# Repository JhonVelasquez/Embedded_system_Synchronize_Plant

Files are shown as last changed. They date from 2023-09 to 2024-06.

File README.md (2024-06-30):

# Embedded_system_Synchronize_Plant
Project of a embedded system  that synchronizes signals in a plant. There is electronic (PCB) and software design (FreeRTOS for STM32F7).

## Required Embedded System - Plant:
The embedded system in the pictures is what is needed for interacting with the Plant, it must send pulses and TCP messages in a specific pattern every time there is a new object incoming the plant.
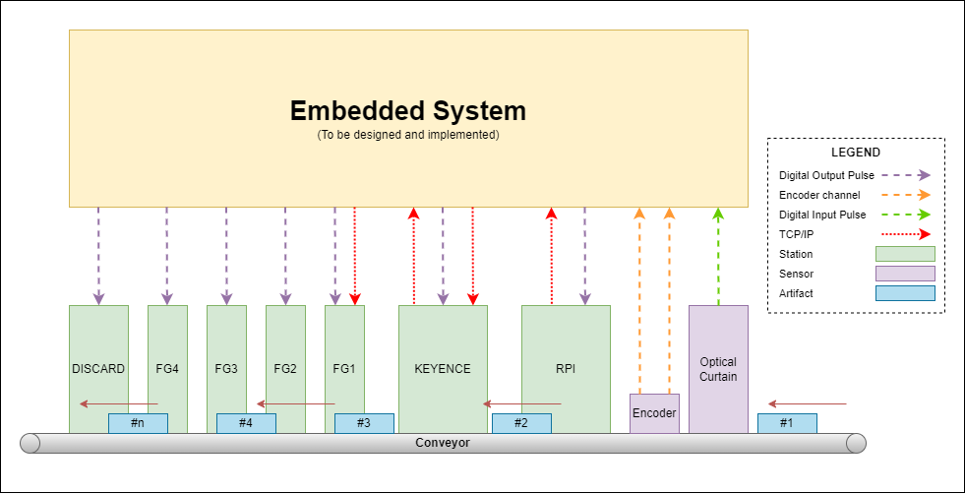
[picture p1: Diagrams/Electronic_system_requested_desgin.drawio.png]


## HARDWARE:

The following PCB collects all the electronics part of the dessigned Embedded system
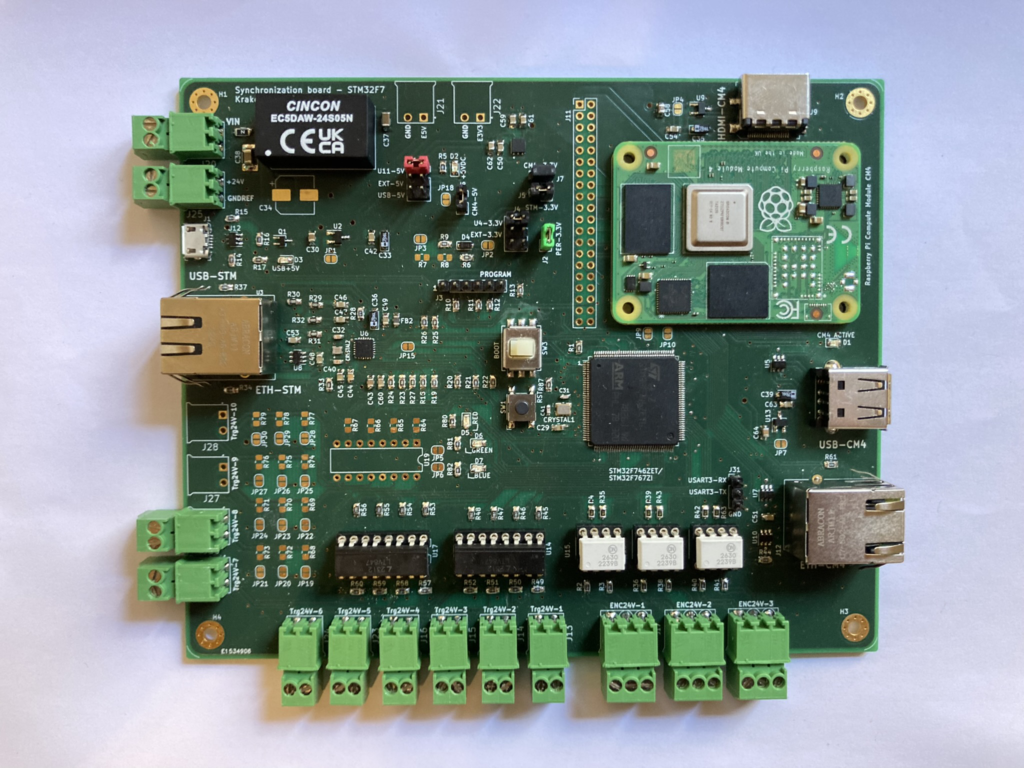
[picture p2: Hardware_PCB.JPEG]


Diagram of the electronics sections. The PCB was made based on it.
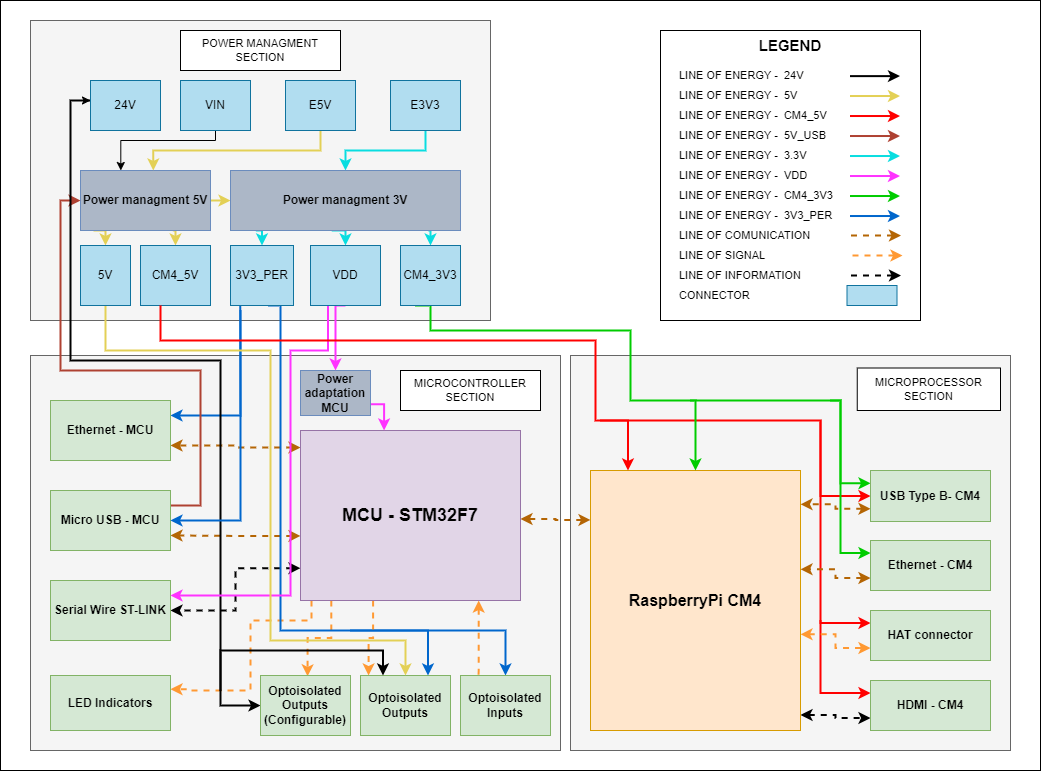
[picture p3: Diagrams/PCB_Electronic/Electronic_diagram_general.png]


Main sub-systems of the PCB
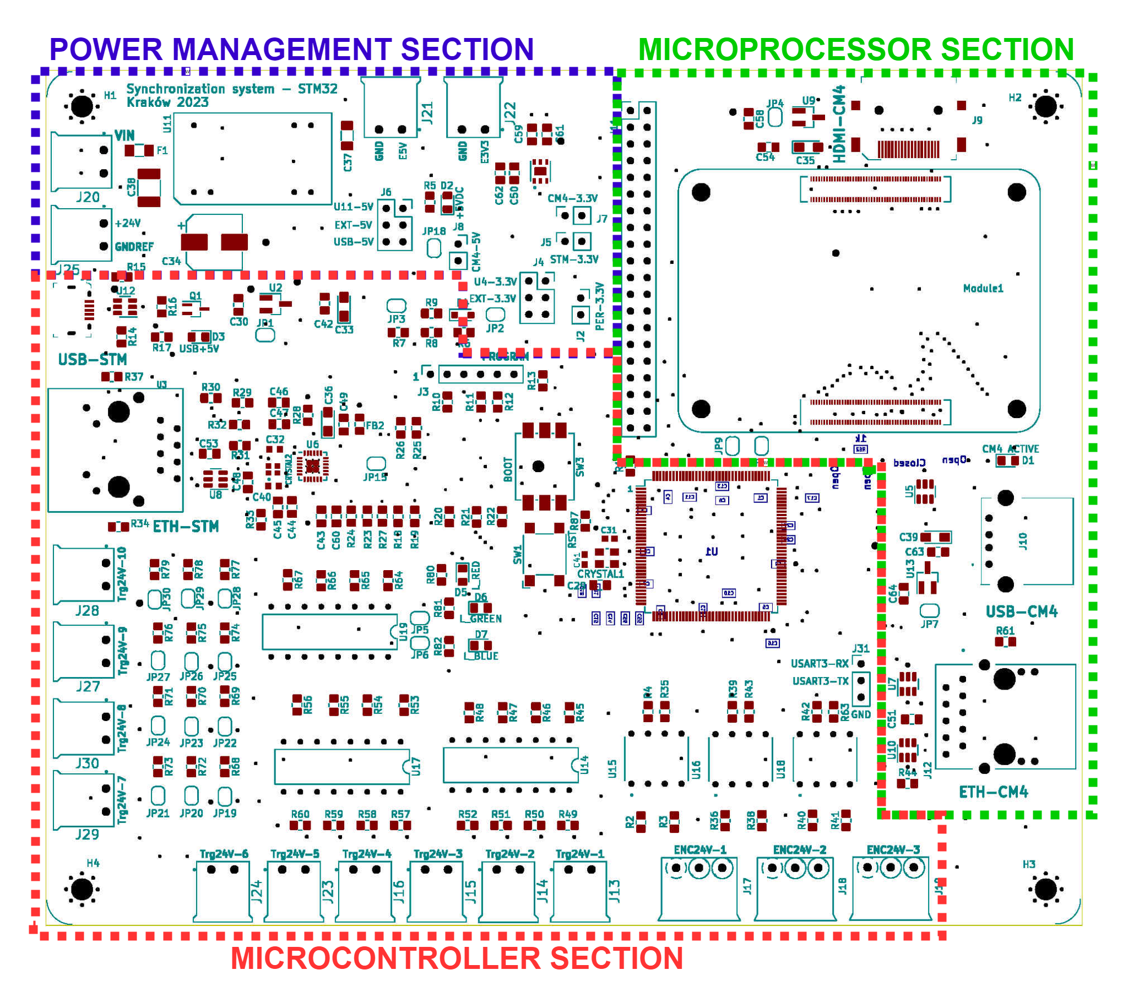
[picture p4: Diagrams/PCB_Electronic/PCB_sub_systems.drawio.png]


## SOFTWARE:

RTOS Architechture:
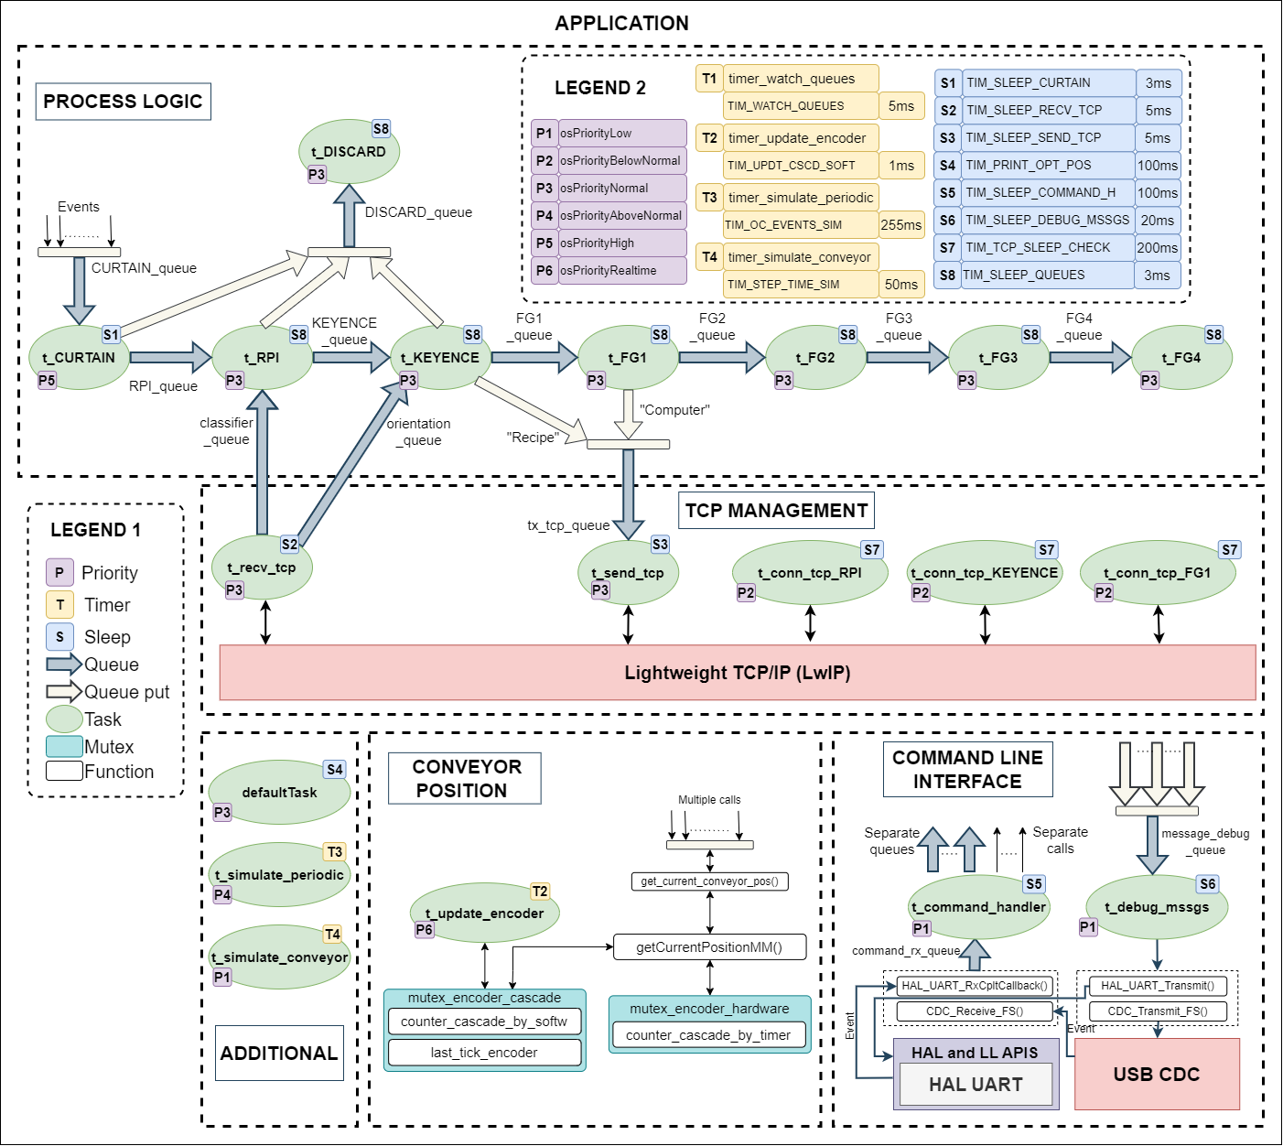
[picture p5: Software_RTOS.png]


CLI command structure:
The CLI for interfacing the microcontroller should have the following structure.
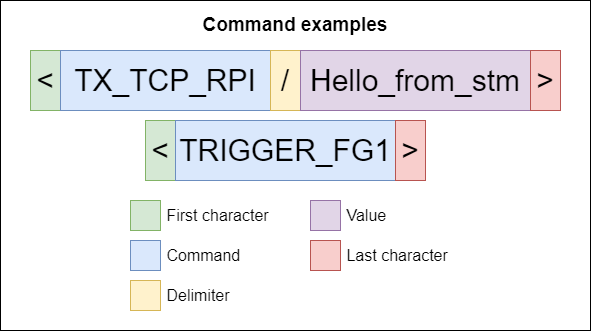
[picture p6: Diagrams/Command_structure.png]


## Integration connections:
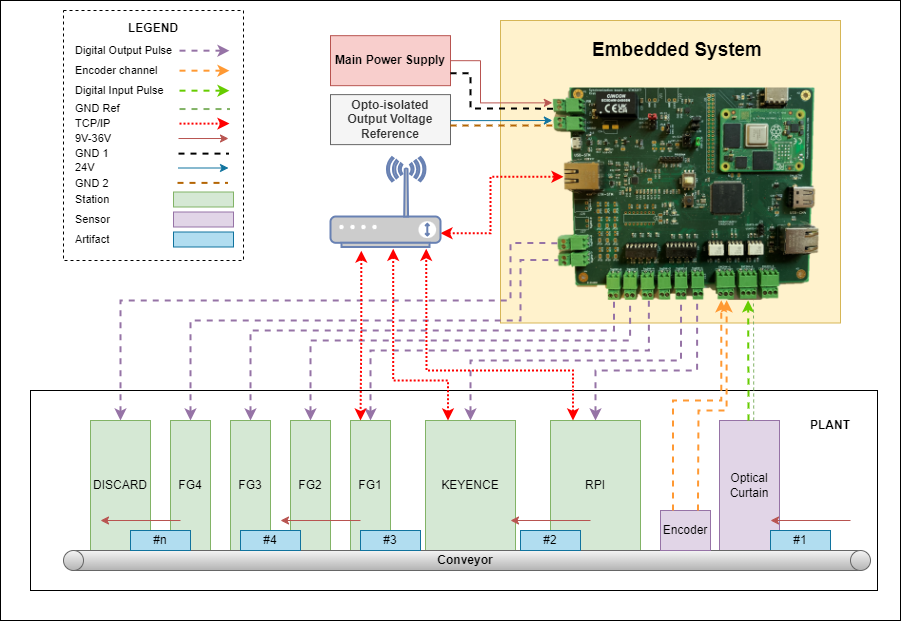
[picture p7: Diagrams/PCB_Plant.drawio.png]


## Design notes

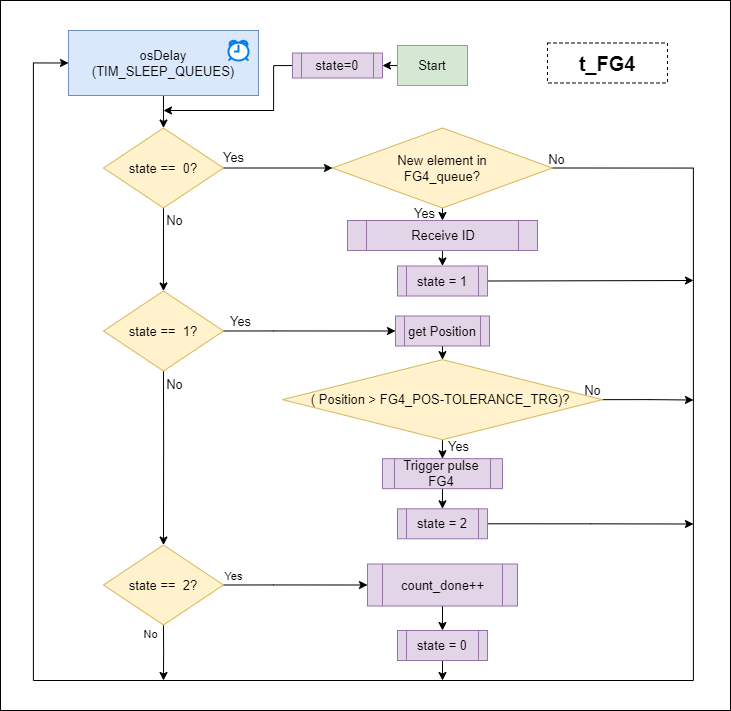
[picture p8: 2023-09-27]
Diagrams/RTOS_Flowchats_Architecture_diagrams/Flowchart_of_task_t_FG4.png

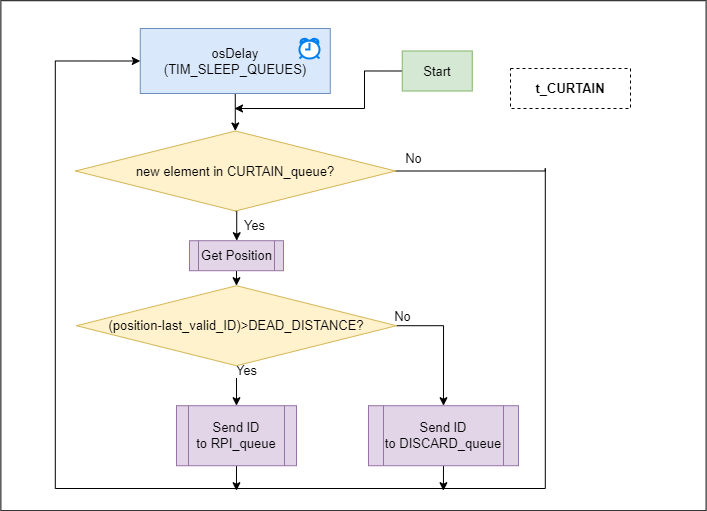
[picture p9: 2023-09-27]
Diagrams/RTOS_Flowchats_Architecture_diagrams/Flowchart_of_task_t_CURTAIN.png

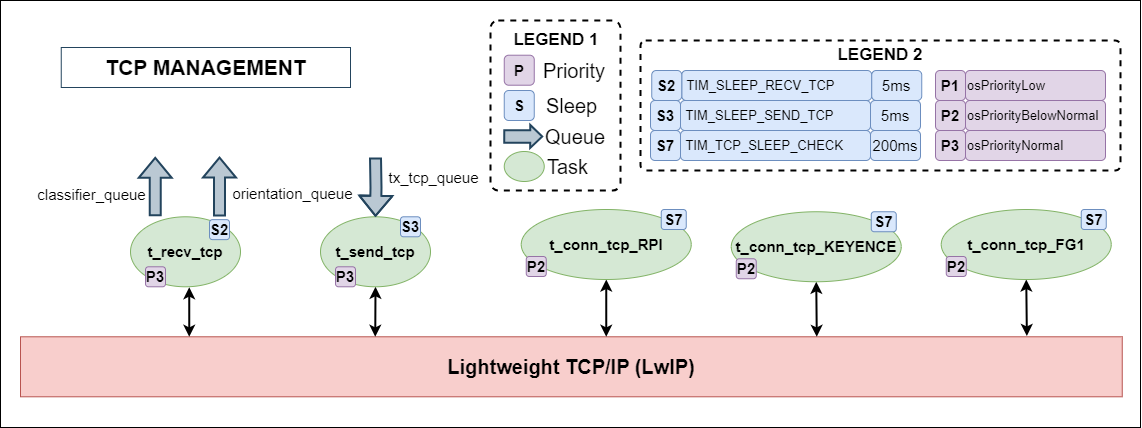
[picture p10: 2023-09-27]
Diagrams/RTOS_Flowchats_Architecture_diagrams/RTOS_TCP_Management_architechture.png

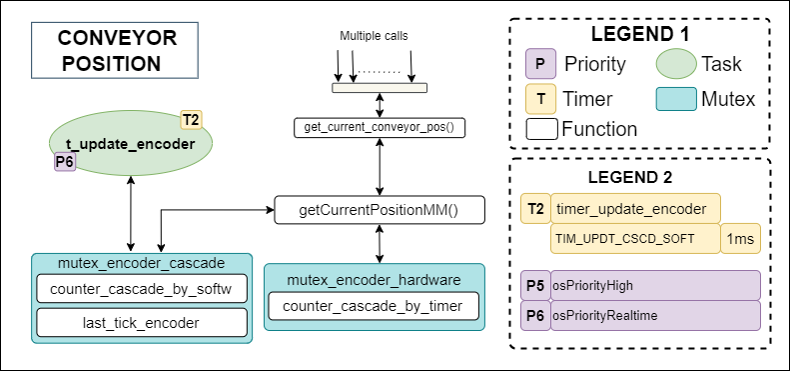
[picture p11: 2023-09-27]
Diagrams/RTOS_Flowchats_Architecture_diagrams/RTOS_TCP_Conveyor_position_architechture.png

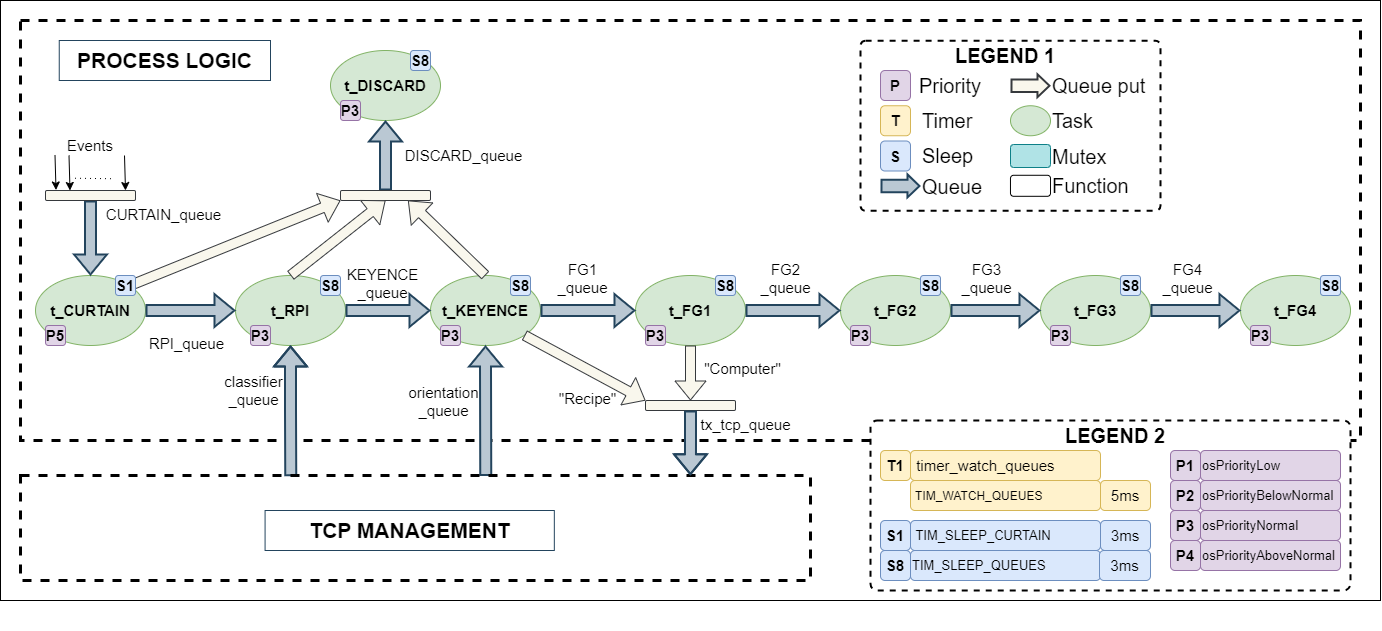
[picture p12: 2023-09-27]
Diagrams/RTOS_Flowchats_Architecture_diagrams/RTOS_TCP_Process_logic.png

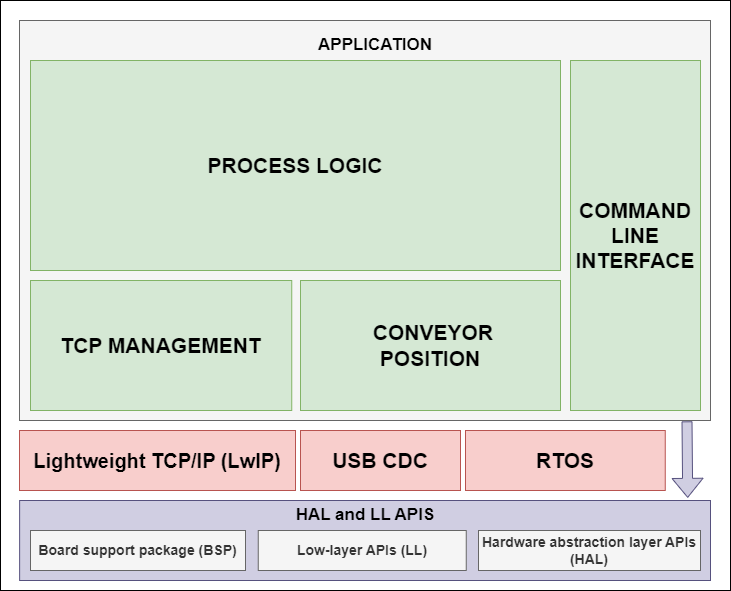
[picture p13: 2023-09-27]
Diagrams/RTOS_Flowchats_Architecture_diagrams/Architecture_system_simplified.png

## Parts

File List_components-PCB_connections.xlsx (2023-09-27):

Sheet: List_components
Power management of 5V
Name | Code | Supplier | Description | Quantity
Voltage regulator | BA50DD0WHFP-TR | digikey | 25v->5v | 1
Power protector | RT9742SNGV | digikey | IC PWR SWITCH N-CHAN 1:1 SOT23-3 | 1
Header 2x6 | PH2-06-UA | digikey | PH2-06-UA | 1
Terminal block 2p female -board | TBG-3.5-KW-2P | TME | Pluggable terminal block; Contacts ph: 3.5mm; ways: 2; angled 90° | 4
Terminal block 2p male | TBG-3.5-AMP-2P |  | Pluggable terminal block; Contacts ph: 3.5mm; ways: 2; straight | 4
C |  |  | Polarized 20uF 25v | 2
C |  |  | Polarized 1uF 25v | 1
R |  |  | 1k ohm | 1
C |  |  | 100nF | 1
C |  |  | 10uF | 1
C |  |  | Polarized 10uF | 1
LED |  |  | GREEN | 1
Power management of 3.3V
Name | Code | Supplier | Description | Quantity
Voltage regulator | LD39050PU33R | digikey | 5v->3.3v | 1
Header 2x6 | PH2-06-UA | digikey | PH2-06-UA | 1
Header 2x1 | PH1-02-UA | digikey |  | 3
C |  |  | 1uF | 2
C |  |  | 100nF | 2
Ethernet - MCU
Name | Code | Supplier | Description | Quantity
Ethernet mac-phy | LAN8742A-EN | ELFA DISTRELEC | Ethernet Transceiver, RMII, QFN-24, Microchip | 1
USB Ethernet line protector | USBLC6-4SC6 | digikey | TVS DIODE 5.25VWM 17VC SOT23-6 | 1
Ethernet connector | ARJM11A3-009-AB-ER2 | digikey | CONN JACK 1PORT 100 BASE-T PCB | 1
Crystal | SXT21422AA07-25.000M | digikey | 25 MHz ±50ppm Crystal 22pF 120 Ohms 4-SMD, No Lead | 1
C | 600S300FT250XT | digikey | Ceramic, high freq, 2*(CL-7) = 30 pF C0G/NP0 0603 | 2
BEAD | 2508056017Y2 | digikey | FERRITE BEAD 600 OHM 0805 1LN | 1
C |  |  | Polarized 10uF | 1
C |  |  | 100nF | 6
C |  |  | 1uF | 1
C |  |  | 10uF | 1
C |  |  | 470pF | 1
R |  |  | 10k ohm | 6
R |  |  | 1.5k ohm | 1
R |  |  | 33 ohm | 4
R |  |  | 50 ohm | 4
R |  |  | 12.1K ohm | 1
R |  |  | 270 ohm | 2
Power Adaptation MCU
Name | Code | Supplier | Description | Quantity
BEAD | 2508056017Y2 | digikey | FERRITE BEAD 600 OHM 0805 1LN | 1
C |  |  | 100nF | 15
C |  |  | 1uF | 4
C |  |  | 2.2uF | 2
C |  |  | 10uF | 1
MCU - STM32F7
Name | Code | Supplier | Description | Quantity
microcontroller | STM32F746ZET6 | kamami | STM32F746ZET6 | 1
Crystal | ECS-80-18-33-JGN-TR | digikey | 8 MHz ±20ppm Crystal CL=18pF 400 Ohms 4-SMD, No Lead | 1
C | CBR06C160F5GAC | digikey | Ceramic, high freq, 2*(CL-10) = 16 pF, C0G, NP0 | 2
Switch | B3FS-101xP |  |  | 1
Button | ESB-33535A | digikey | ESB-33535A | 1
C |  |  | 100nF | 1
R |  |  | 10k ohm | 1
Serial Wire ST-LINK
Name | Code | Supplier | Description | Quantity
Diode | BAT60AE6327HTSA1 | digikey | DIODE SCHOTTKY 10V 3A SOD323-2 | 1
Header 1x6 | PH1-06-UA | digikey | PH1-06-UA | 1
R |  |  | 22 ohm | 4
R |  |  | 1k ohm | 2
R |  |  | 2.7k ohm | 2
R |  |  | 4.7k ohm | 2
R |  |  | 10k ohm | 1
R |  |  | 100 ohm | 1
Micro USB - MCU
Name | Code | Supplier | Description | Quantity
Micro USB | 10118194-0001LF | digikey | CONN RCPT USB2.0 MICRO B SMD R/A | 1
USB Ethernet line protector | USBLC6-4SC6 | digikey | TVS DIODE 5.25VWM 17VC SOT23-6 | 1
Transistor | BC847CW,115 | digikey | BC847CW,115 | 1
R |  |  | 47k ohm | 2
R |  |  | 22k ohm | 1
R |  |  | 330 ohm | 1
LED |  |  | GREEN | 1
LED Indicators
Name | Code | Supplier | Description | Quantity
Header 1x3 | PH1-03-UA |  |  | 1
LED |  |  | RED | 1
LED |  |  | GREEN | 1
LED |  |  | BLUE | 1
R |  |  | 1k ohm | 2
R |  |  | 330 ohm | 1
Opto-isolated Outputs, Outputs (configurable), and Inputs
Name | Code | Supplier | Description | Quantity
Optoizolator 2 kanałowy, 10 Mbit/s | HCPL2630M | TME | Encoders connections x4 | 3
Optoizolator 4 kanałowy, OC | LTV-847 | TME | Lines triggerring x8 | 3
Podstawka GOLD-8P | GOLD-8P | TME | Base for opto 8p | 3
Podstawka GOLD-16P | GOLD-16P | TME | Base for opto 16p | 3
Terminal block 2p female -board | TBG-3.5-KW-2P | TME | Pluggable terminal block; Contacts ph: 3.5mm; ways: 2; angled 90° | 10
Terminal block 2p male | TBG-3.5-AMP-2P |  | Pluggable terminal block; Contacts ph: 3.5mm; ways: 2; straight | 10
Terminal block 3p male -board |  | TME | Pluggable terminal block; Contacts ph: 3.5mm; ways: 2; angled 90° | 3
Terminal block 3p female -board |  | TME | Pluggable terminal block; Contacts ph: 3.5mm; ways: 2; angled 90° | 3
R |  |  | 2.2k ohm | 18
R |  |  | 210 ohm | 18
R |  |  | 330 ohm | 4
R |  |  | 470 ohm | 4
Raspberry Pi CM4, HAT Connector, and Ethernet CM4
Name | Code | Supplier | Description | Quantity
Raspberrry CM4 |  | digikey |  | 1
Header 2x20 | PH2-20-UA | digikey | PH2-06-UA | 2
Rpi MC4 connector female board | DF40HC (3.0) -100DS-0.4V(51) | digikey | DF40C-100DP-0.4V(51) | 2
LED |  |  | GREEN | 1
R |  |  | 1k ohm | 1
Ethernet - CM4
Name | Code | Supplier | Description | Quantity
USB Ethernet line protector | USBLC6-4SC6 | digikey | TVS DIODE 5.25VWM 17VC SOT23-6 | 2
Ethernet port | ARJM11C7-502-AB-ER2-T | digikey | CONN JACK 1PORT 1000 BASE-T PCB | 1
C |  |  | 100nF | 1
R |  |  | 470 ohm | 2
USB Type B - CM4
Name | Code | Supplier | Description | Quantity
usb female | USB-A1HSB6 | digikey | CONN RCPT TYPEA 4POS R/A | 1
Power protector | RT9742SNGV | digikey | IC PWR SWITCH N-CHAN 1:1 SOT23-3 | 1
USB Ethernet line protector | USBLC6-4SC6 | digikey | TVS DIODE 5.25VWM 17VC SOT23-6 | 1
C |  |  | Polarized 10uF | 1
C |  |  | 100nF | 1
C |  |  | 10uF | 1
HDMI - CM4
Name | Code | Supplier | Description | Quantity
HDMI connector | 2000-1-2-41-00-BK | digikey | CONN RCPT HDMI 19POS SMD R/A | 1
Power protector | RT9742SNGV | digikey | IC PWR SWITCH N-CHAN 1:1 SOT23-3 | 1
C |  |  | Polarized 10uF | 1
C |  |  | 100nF | 1
C |  |  | 10uF | 1
Raspberrry CM4
Name | Code | Supplier | Description | Quantity
Nano Base Board (B) for CM4 | Nano Base Board (B) - ekspander | botland | Pin expander | 1

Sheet: MCU Pinout
 |  |  | MCU - ETHERNET PERIPHERIAL
 |  |  | ETH_TXD0 | PG13
 |  |  | ETH_TXD1 | PB13
 |  |  | ETH_TX_EN | PG11
 |  |  | ETH_RXD0 | PC4
 |  |  | ETH_RXD1 | PC5
 |  |  | ETH_CRS_DV | PA7
 |  |  | ETH_MDIO | PA2
 |  |  | ETH_MDC | PC1
 |  |  | ETH_REF_CLK | PA1
TRIGGER GPIO - OUTPUT
Connector | Pin | Schematic End | Schematic MCU | GPIO PIN | USE
Trg24V-1 | 1 | TRIGGER_24V_1 | TRIGGER_GPIO_1 | PE15 | TRIGGER_RPI
Trg24V-2 | 1 | TRIGGER_24V_2 | TRIGGER_GPIO_2 | PE14 | TRIGGER_KEYENCE
Trg24V-3 | 1 | TRIGGER_24V_3 | TRIGGER_GPIO_3 | PE13 | SIMULATE_ENCODER_CH2
Trg24V-4 | 1 | TRIGGER_24V_4 | TRIGGER_GPIO_4 | PE12 | TRIGGER_FG1
Trg24V-5 | 1 | TRIGGER_24V_5 | TRIGGER_GPIO_5 | PE11 | TRIGGER_FG2
Trg24V-6 | 1 | TRIGGER_24V_6 | TRIGGER_GPIO_6 | PE10 | TRIGGER_FG3
Trg24V-7 | 1 | TRIGGER_24V_7 | TRIGGER_GPIO_7 | PE9 | TRIGGER_FG4
Trg24V-8 | 1 | TRIGGER_24V_8 | TRIGGER_GPIO_8 | PE8 | TRIGGER_DISCARD
Trg24V-9 | 1 | TRIGGER_xxV_9 | TRIGGER_GPIO_9 | PE6
Trg24V-9 | 2 | TRIGGER_xxV_10 | TRIGGER_GPIO_10 | PE5
Trg24V-10 | 1 | TRIGGER_xxV_11 | TRIGGER_GPIO_11 | PE4
Trg24V-10 | 2 | TRIGGER_xxV_12 | TRIGGER_GPIO_12 | PE3
ENCODER GPIO - INPUT
Connector | Pin | Schematic End | Schematic MCU | GPIO PIN | USE
ENC24V_1 | 1 | ENC_24V_1 | ENC_GPIO_1 | PB14
ENC24V_1 | 2 | ENC_24V_2 | ENC_GPIO_2 | PB15
ENC24V_2 | 1 | ENC_24V_3 | ENC_GPIO_3 | PD10
ENC24V_2 | 2 | ENC_24V_4 | ENC_GPIO_4 | PD11 | OPTICAL_CURTAIN
ENC24V_3 | 1 | ENC_24V_5 | ENC_GPIO_5 | PD12 | ENCODER_TIM4_CH1
ENC24V_3 | 2 | ENC_24V_6 | ENC_GPIO_6 | PD13 | ENCODER_TIM4_CH2
 |  |  | ADDITIONAL
 |  |  | NRST | NRST
 |  |  | BOOT0 | BOOT0
 |  |  | USB
 |  |  | Schematic MCU | GPIO PIN | USE
 |  |  | USB_DM_- | PA11 | USB_OTG_FS
 |  |  | USB_DM_+ | PA12 | USB_OTG_FS
 |  |  | SERIAL WIRE PERIPHERAL
 |  |  | SWDIO | PA13
 |  |  | SWCLK | PA14
 |  |  | SWO | PB3
 |  | SERIAL TO CM4
 |  | Schematic End | Schematic MCU | GPIO PIN
 |  | CM4_TXD3 (Connected by default) | UART5_RX | PD2
 |  | CM4_RXD3 (Connected by default) | UART5_TX | PC12
 |  | CM4_TXD0 (Disconnected) | USART6_RX | PC7
 |  | CM4_RXD0 (Disconnected) | USART6_TX | PC6
 |  | J31 Con01x03 | USART3_RX | PD9 | CLI
 |  | J31 Con01x03 | USART3_TX | PD8 | CLI
 |  |  | INDICATOR
 |  |  | Schematic MCU | GPIO PIN | USE
 |  |  | INDICATOR_RED | PB0 | INDICATOR_R_GPIO
 |  |  | INDICATOR_GREEN | PB1 | INDICATOR_G_GPIO
 |  |  | INDICATOR_BLUE | PB2 | INDICATOR_B_GPIO
 |  | PCB OUTPUTS
 |  | PCB connector | PCB connector Pin | Schematic Tag | GPIO PIN | Software Use
 |  | Trg24V-1 | 1 | TRIGGER_24V_1 | PE15 | TRIGGER_RPI
 |  | Trg24V-2 | 1 | TRIGGER_24V_2 | PE14 | TRIGGER_KEYENCE
 |  | Trg24V-3 | 1 | TRIGGER_24V_3 | PE13 | SIMULATE_ENCODER_CH2
 |  | Trg24V-4 | 1 | TRIGGER_24V_4 | PE12 | TRIGGER_FG1
 |  | Trg24V-5 | 1 | TRIGGER_24V_5 | PE11 | TRIGGER_FG2
 |  | Trg24V-6 | 1 | TRIGGER_24V_6 | PE10 | TRIGGER_FG3
 |  | Trg24V-7 | 1 | TRIGGER_24V_7 | PE9 | TRIGGER_FG4
 |  | Trg24V-8 | 1 | TRIGGER_24V_8 | PE8 | TRIGGER_DISCARD
 |  | Trg24V-9 | 1 | TRIGGER_xxV_9 | PE6 | -
 |  | Trg24V-9 | 2 | TRIGGER_xxV_10 | PE5 | -
 |  | Trg24V-10 | 1 | TRIGGER_xxV_11 | PE4 | -
 |  | Trg24V-10 | 2 | TRIGGER_xxV_12 | PE3 | -
 |  | ENC24V_1 | 1 | ENC_24V_1 | PB14 | -
 |  | ENC24V_1 | 2 | ENC_24V_2 | PB15 | -
 |  | ENC24V_2 | 1 | ENC_24V_3 | PD10 | -
 |  | ENC24V_2 | 2 | ENC_24V_4 | PD11 | OPTICAL_CURTAIN
 |  | ENC24V_3 | 1 | ENC_24V_5 | PD12 | ENCODER_CH1
 |  | ENC24V_3 | 2 | ENC_24V_6 | PD13 | ENCODER_CH2
 |  |  |  |  | PB0 | INDICATOR_R_GPIO
 |  |  |  |  | PB1 | INDICATOR_G_GPIO
 |  |  |  |  | PB2 | INDICATOR_B_GPIO

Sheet: CLI_commands
Number | Header | Payload | Description
1 | EN_ACK_POS | {true, false} | Enable or disable the periodic position printing in CLI
2 | TRIGGER_OPTICAL_EVENT | - | Simulates the event of Optical Curtain trigger
3 | TRIGGER_RPI | - | Sends a pulse to RPI station
4 | TRIGGER_KEYENCE | - | Sends a pulse to KEYENCE station
5 | TRIGGER_FG1 | - | Sends a pulse to FG1 station
6 | TRIGGER_FG2 | - | Sends a pulse to FG2 station | s
7 | TRIGGER_FG3 | - | Sends a pulse to FG3 station
8 | TRIGGER_FG4 | - | Sends a pulse to FG4 station
9 | TRIGGER_DISCARD | - | Sends a pulse to DISCARD station
10 | TX_TCP_RPI | Any string message | Sends the Payload as message through TCP to RPI station
11 | TX_TCP_KEYENCE | Any string message | Sends the Payload as message through TCP to KEYENCE station
12 | TX_TCP_FG1 | Any string message | Sends the Payload as message through TCP to FG1 station
13 | CLASSIFIER | Classifier message | Sends the Payload to the classifier_queue
14 | ORIENTATION | Orientation format | Sends the Payload to the orientation_queue
Number | Header | Payload | Description
1 | ECHO | Any string message | Response to a CLI command
2 | ERRO | Any string message | Shows an error information
3 | SCSS | Any string message | Shows a successful operation information
4 | ACKN | Any string message | Shows an informative message
5 | TCPC | Any string message | Shows a message regarding TCP connections

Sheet: PCB-INTERFACE
Power Management - PCB Interfaces
Code | Tag | Type | Use | Description
J20 | VIN | Connector | Power source | Main [9-25]V
J25 | +24V | Connector | Power source | 24V for optocouplers
J21 | E5V | Connector | Power source | External 5V optional
J22 | E3V3 | Connector | Power source | External 3.3V optional
J6 | 5V_sel | Header 3x2 | Selector | Among converted VIN, USB-STM 5V, and E5V for Main internal 5V.
J8 | CM4-5V | Header 1x2 | Enable | CM4 subsystem power
J4 | 3.3V_sel | Header 3x2 | Selector | Among converted Main internal 5V, and E3V3 for Main internal 3.3V
J5 | STM-3.3V | Header 1x2 | Enable | MCU power
J2 | PER-3.3V | Header 1x2 | Enable | MCU peripherals power
J7 | CM4-3.3V | Header 1x2 | Enable | RPi HAT 3.3V power
Micocotroller - PCB Interfaces
Code | Tag | Type | Use | Description
J1 | USB-STM | Micro USB | USB | -
U3 | ETH-STM | RJ45 | Ethernet | Fast Ethernet (100Mbps) and 10BASE-T (10Mbps)
J3 | PROGRAM | Header 1x6 | ST-Link | Pin 1, VDD. Pin 2, CLK. Pin 3, GND. Pin 4, DIO. Pin 5, RST. Pin 6, SWO.
SW3 | BOOT | Switch | MCU Input | Used for MCU booting selection
SW1 | RST | Switch | MCU Input | Used for MCU, ST-Link Ethernet reset
J31 | UART_DEBUG | Header 1x3 | Serial | MCU UART3. Pin 1, RX. Pin 2, TX. Pin 3, GND.
D5 | L_RED | LED | Indicator | Indicator. PB0.
D6 | L_GREEN | LED | Indicator | Indicator. PB1.
D7 | L_BLUE | LED | Indicator | Indicator. PB2.
J13 | Trg24V-1 | Connector | Signal | Output 24V. Pin 1, PE15. Pin2, +24v.
J14 | Trg24V-2 | Connector | Signal | Output 24V. Pin 1, PE14. Pin2, +24v.
J15 | Trg24V-3 | Connector | Signal | Output 24V. Pin 1, PE13. Pin2, +24v.
J16 | Trg24V-4 | Connector | Signal | Output 24V. Pin 1, PE12. Pin2, +24v.
J23 | Trg24V-5 | Connector | Signal | Output 24V. Pin 1, PE11. Pin2, +24v.
J24 | Trg24V-6 | Connector | Signal | Output 24V. Pin 1, PE10. Pin2, +24v.
J29 | Trg24V-7 | Connector | Signal | Output 24V. Pin 1, PE9. Pin2, +24v.
J30 | Trg24V-8 | Connector | Signal | Output 24V. Pin 1, PE8. Pin2, +24v.
J27 | Trg24V-9 | Connector | Signal | Output 24V. Pin 1, PE6. Pin2, PE5.
J28 | Trg24V-10 | Connector | Signal | Output 24V. Pin 1, PE4. Pin2, PE3.
J17 | ENC24V_1 | Connector | Signal | Input 24V. Pin 1, PB14. Pin 2, PB15. Pin 3, Ref_Level_1.
J18 | ENC24V_2 | Connector | Signal | Input 24V. Pin 1, PD10. Pin 2, PD11. Pin 3, Ref_Level_1.
J19 | ENC24V_3 | Connector | Signal | Input 24V. Pin 1, PD12. Pin 2, PD13. Pin 3, Ref_Level_1.
CM4 - PCB Interfaces
Code | Tag | Type | Use | Description
J9 | HDMI-CM4 | Standard | HDMI | CM4 HDMI interface
J10 | USB-CM4 | USB Type A | USB | CM4 USB interface
J12 | ETH-CM4 | RJ45 | Ethernet | Gigabit Ethernet (1000Mbps)

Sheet: Pasive_components_list
Name | Board | Code | Supplier | Description | New Quanitty | Component
C | SMD 0805 | CC0805KPX7R9104 |  | 100nF | 28 | check
C | SMD 0805 | CL21B106KPQNNNE |  | 10uF | 5 | check
C | SMD 0805 | CC0805KKX7R8105 |  | 1uF | 7 | check
C | SMD 0805 | CL21B225KOFNNNE |  | 2.2uF | 2 | check
C | SMD 0805 | 0805B471K500CT |  | 470pF | 1 | check
C | SMD A | 293D106X06R3A2TE3 | digikey | Polarized 10uF | 4
C | SMD A | 293D105X0016A2TE3 |  | Polarized 1uF 16v | 1 | check
C | Electrolytic | EEEHA1J220UP | digikey | Polarized 20uF 25v | 2
LED | SMD 0805 | Green lub inny kolor, SMD 0805 |  | GREEN | 4 | check
LED | SMD 0805 |  |  | RED | 1
LED | SMD 0805 |  |  | BLUE | 1
R | SMD 0805 |  |  | 1.5k ohm | 1 | check
R | SMD 0805 |  |  | 100 ohm | 1 | check
R | SMD 0805 |  |  | 10k ohm | 8 | check
R | SMD 0805 |  |  | 12.1K ohm | 1 | check
R | SMD 0805 |  |  | 1k ohm | 8 | check
R | SMD 0805 |  |  | 2.2k ohm | 18
R | SMD 0805 |  |  | 210 ohm | 18
R | SMD 0805 |  |  | 22 ohm | 4 | check
R | SMD 0805 |  |  | 22k ohm | 1 | check
R | SMD 0805 |  |  | 270 ohm | 2 | check
R | SMD 0805 |  |  | 33 ohm | 4 | check
R | SMD 0805 |  |  | 330 ohm | 6 | check
R | SMD 0805 |  |  | 2.7k ohm | 2 | check
R | SMD 0805 |  |  | 4.7k ohm | 2
R | SMD 0805 |  |  | 470 ohm | 6 | check
R | SMD 0805 |  |  | 47k ohm | 2
R | SMD 0805 |  |  | 49.9 ohm | 4 | check
 |  |  |  |  | 144
5V tolerance for C without requirement
non-polarized for C without requirement

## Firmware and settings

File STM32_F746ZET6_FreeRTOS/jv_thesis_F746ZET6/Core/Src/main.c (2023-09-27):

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
/* Includes ------------------------------------------------------------------*/
#include "main.h"
#include "cmsis_os.h"
#include "lwip.h"
#include "usb_device.h"

/* USER CODE BEGIN Includes */

#include "define.h"
#include "utils.h"
#include "stdio.h"
#include "tagging.h"
#include "trigger.h"

//tcp
#include "lwip/opt.h"
#include "lwip/api.h"
#include "lwip/sys.h"
//#include "tcpclient.h"
#include "string.h"
#include "stdbool.h"
#include "tcpbase.h"
#include "tcp.h"
#include "usbd_cdc_if.h"

#include "structures.h"
/* USER CODE END Includes */

/* USER CODE BEGIN PD */

////////////////////////////
/*GENERAL VARIABLES*/
////////////////////////////



bool use_simulator = USE_SIMULATOR_CONVEYOR;
//Simulator conveyor position
float last_optical_curtain = 0; //last optical recorded position
bool en_ackn_pos = USE_ACK_CONVEYOR_POS; //enable optical curtain debug
float sim_opt_curt_mm = 0; //simulated value

//Simulator OC events
bool en_period_oc_event_sim = USE_OC_EVENTS_SIM; //enable optical curtain debug
bool en_period_oc_print = false;
bool en_period_oc_event_sim_last = USE_OC_EVENTS_SIM;

//Task t_update_encoder
int16_t tick_encoder_var = 0;
int16_t last_tick_encoder = 0;

int32_t counter_cascade_by_softw = 0; // implemented by software counts overflow and underflow
int32_t counter_cascade_by_timer = 0; // implemented by TIM slave, it counts only passing by overflow


/*GENERAL*/
float get_current_conveyor_pos();

//////////////
/*DEAULT TASK*/
//////////////


//////////////
/*STATIONS*/
//////////////

//general
typedef struct {
	uint8_t classifier[MAX_STATIONS_TCP];
	uint8_t orientation[MAX_STATIONS_TCP];
	float optical_curtain;
} queue_inter_stations;

typedef struct {
	char msg[MAX_STATIONS_TCP];
} queue_stations_tcp;

float count_discard = 0;
float count_done = 0;
float count_total_OC_events = 0;
float count_total_OC_trigger_sim = 0;

float sim_per_oc_start_pos =0;
float sim_per_oc_end_pos =0;
/*RPI*/
void send_to_CLASSIFIER_queue(char * value);
/*KEYENCE*/
void send_to_ORIENTATION_queue(char * value);

//////////////
/*TCP*/
//////////////

typedef struct {
	uint8_t msg[BUFFER_TCP_TX_SIZE];
	struct netconn *conn;
	char * point_conn_name;
} queue_tx_rx_tcp;

static struct netconn *conn_RPI;
static struct netconn *conn_KEYENCE;
static struct netconn *conn_FG1;

char smsgc_rx_tcp_buff_debug[MAX_MESSSAGE_SIZE];
char smsgc_tx_tcp_buff_debug[MAX_MESSSAGE_SIZE];
extern ip4_addr_t ipaddr;


const char str_RPI[] = "RPI";
const char str_KEYENCE[] = "KEYENCE";
const char str_FG1[] = "FG1";

/*SEND_TCP*/
osStatus_t send_tcp_to_station(char* value, char * str_station_name, struct netconn *conn_var);
void send_tcp_to_RPI(char* value);
void send_tcp_to_KEYENCE(char* value);
void send_tcp_to_FG1(char* value);

/*RECV_TCP*/
void recv_tcp(char * str_conn_name, char * msgc, struct netbuf *buf, struct netconn *conn);

/*CONN_MONITOR_TCP*/
void conn_init_monitor_tcp(char * str_conn_name, struct netconn **pointer_conn, ip4_addr_t* sourc_addr, unsigned short sourc_port, ip4_addr_t dest_addr, unsigned short dest_port);


////////////////////////////
/* CONVEYOR POSITION */
////////////////////////////
void callback_trigger_optical_curtain();
void callback_trigger_optical_curtain_IT();
void evaluate_optical_curtain();
bool fixed_value_optical_curtain=true;

double conveyor_pos=0;

////////////////////////////
/* UART COMMANDS DEBUG*/
////////////////////////////

//external HAL_UART_RxCpltCallback
uint8_t rxBuffer;
UART_HandleTypeDef* huart_CLI_debug;
UART_HandleTypeDef* huart_CLI_CM4_main;
UART_HandleTypeDef* huart_CLI_CM4_second;

//local HAL_UART_RxCpltCallback
uint8_t state_rx=0;
uint8_t cnt_rx;
queue_commandRx queueCommandRx;



//extern USBD_HandleTypeDef hUsbDeviceFS;
uint8_t rxBuffer_USB;
cli_char_buffer_handler cli_uart_debug;
cli_char_buffer_handler cli_uart_CM4_main;
cli_char_buffer_handler cli_uart_CM4_second;
cli_char_buffer_handler cli_usb;



//external debug_send_.....
typedef struct{
	char content[TX_SIZE_UART_DEBUG];
	char * type;
} message_debug;

const char str_start_mssg = COMMAND_HANDLER_START;
const char str_delimiter_mssg = COMMAND_HANDLER_DELIMITER;
const char str_end_mssg = COMMAND_HANDLER_END;

//local debug_send_.....
const char str_echo[] = "ECHO";
const char str_error[] = "ERRO";
const char str_success[] = "SCSS";
const char str_ack[] = "ACKN";
const char str_n_r[] = "\n\r";
int str_n_r_size = strlen(str_n_r);
const char str_tcp[] = "TCPC";


char var_debug_send_optical[20];

///////////////////////////////////
/*DEBUG_MESSAGES*/
///////////////////////////////////
void debug_send_echo(char * txBuffer);
void debug_send_error(char * txBuffer);
void debug_send_success(char * txBuffer);
void debug_send_ack(char * txBuffer);
void debug_send_tcp(char * txBuffer);
void debug_tcp_connection_state(uint8_t state);
void debug_message_sent_tcp(uint8_t state, queue_tx_rx_tcp *ms);
void debug_message_recv_tcp(char *str_conn_name, char *msgc);
void debug_init_monitor_tcp(char * str_conn_name);
void debug_lost_monitor_tcp(char * str_conn_name);
void debug_send_queue_result(osStatus_t r, char * txBuffer);
void debug_send_process(char * str_type,float optical_curtain_id, float rel_dist, char * txBuffer);
void debug_send_queue_process_result(osStatus_t r, float starting_pos_local, float relative_pos_local, char * txBuffer);
void debug_send_optical_position(float t);
void debug_send_done_discard();
/* USER CODE END PD */


TIM_HandleTypeDef htim1;
TIM_HandleTypeDef htim3;
TIM_HandleTypeDef htim4;
TIM_HandleTypeDef htim5;

UART_HandleTypeDef huart5;
UART_HandleTypeDef huart3;
UART_HandleTypeDef huart6;

/* Definitions for defaultTask */
osThreadId_t defaultTaskHandle;
const osThreadAttr_t defaultTask_attributes = {
  .name = "defaultTask",
  .stack_size = 2048 * 4,
  .priority = (osPriority_t) osPriorityBelowNormal,
};
/* Definitions for t_RPI_watch */
osThreadId_t t_RPI_watchHandle;
const osThreadAttr_t t_RPI_watch_attributes = {
  .name = "t_RPI_watch",
  .stack_size = 512 * 4,
  .priority = (osPriority_t) osPriorityNormal,
};
/* Definitions for t_KEYENCE_watch */
osThreadId_t t_KEYENCE_watchHandle;
const osThreadAttr_t t_KEYENCE_watch_attributes = {
  .name = "t_KEYENCE_watch",
  .stack_size = 512 * 4,
  .priority = (osPriority_t) osPriorityNormal,
};
/* Definitions for t_FG1_wach */
osThreadId_t t_FG1_wachHandle;
const osThreadAttr_t t_FG1_wach_attributes = {
  .name = "t_FG1_wach",
  .stack_size = 512 * 4,
  .priority = (osPriority_t) osPriorityNormal,
};
/* Definitions for t_FG2_wach */
osThreadId_t t_FG2_wachHandle;
const osThreadAttr_t t_FG2_wach_attributes = {
  .name = "t_FG2_wach",
  .stack_size = 256 * 4,
  .priority = (osPriority_t) osPriorityNormal,
};
/* Definitions for t_FG3_wach */
osThreadId_t t_FG3_wachHandle;
const osThreadAttr_t t_FG3_wach_attributes = {
  .name = "t_FG3_wach",
  .stack_size = 256 * 4,
  .priority = (osPriority_t) osPriorityNormal,
};
/* Definitions for t_FG4_wach */
osThreadId_t t_FG4_wachHandle;
const osThreadAttr_t t_FG4_wach_attributes = {
  .name = "t_FG4_wach",
  .stack_size = 256 * 4,
  .priority = (osPriority_t) osPriorityNormal,
};
/* Definitions for t_DISCARD */
osThreadId_t t_DISCARDHandle;
const osThreadAttr_t t_DISCARD_attributes = {
  .name = "t_DISCARD",
  .stack_size = 256 * 4,
  .priority = (osPriority_t) osPriorityNormal,
};
/* Definitions for t_command_hand */
osThreadId_t t_command_handHandle;
const osThreadAttr_t t_command_hand_attributes = {
  .name = "t_command_hand",
  .stack_size = 256 * 4,
  .priority = (osPriority_t) osPriorityLow,
};
/* Definitions for t_send_tcp */
osThreadId_t t_send_tcpHandle;
const osThreadAttr_t t_send_tcp_attributes = {
  .name = "t_send_tcp",
  .stack_size = 1024 * 4,
  .priority = (osPriority_t) osPriorityBelowNormal,
};
/* Definitions for t_recv_tcp */
osThreadId_t t_recv_tcpHandle;
const osThreadAttr_t t_recv_tcp_attributes = {
  .name = "t_recv_tcp",
  .stack_size = 1024 * 4,
  .priority = (osPriority_t) osPriorityBelowNormal,
};
/* Definitions for t_conn_tcp_RPI */
osThreadId_t t_conn_tcp_RPIHandle;
const osThreadAttr_t t_conn_tcp_RPI_attributes = {
  .name = "t_conn_tcp_RPI",
  .stack_size = 1024 * 4,
  .priority = (osPriority_t) osPriorityBelowNormal,
};
/* Definitions for t_conn_tcp_KEYENCE */
osThreadId_t t_conn_tcp_KEYENCEHandle;
const osThreadAttr_t t_conn_tcp_KEYENCE_attributes = {
  .name = "t_conn_tcp_KEYENCE",
  .stack_size = 1024 * 4,
  .priority = (osPriority_t) osPriorityBelowNormal,
};
/* Definitions for t_conn_tcp_FG1 */
osThreadId_t t_conn_tcp_FG1Handle;
const osThreadAttr_t t_conn_tcp_FG1_attributes = {
  .name = "t_conn_tcp_FG1",
  .stack_size = 1024 * 4,
  .priority = (osPriority_t) osPriorityBelowNormal,
};
/* Definitions for t_simulate_conveyor */
osThreadId_t t_simulate_conveyorHandle;
const osThreadAttr_t t_simulate_conveyor_attributes = {
  .name = "t_simulate_conveyor",
  .stack_size = 128 * 4,
  .priority = (osPriority_t) osPriorityLow,
};
/* Definitions for t_debug_mssgs */
osThreadId_t t_debug_mssgsHandle;
const osThreadAttr_t t_debug_mssgs_attributes = {
  .name = "t_debug_mssgs",
  .stack_size = 256 * 4,
  .priority = (osPriority_t) osPriorityLow,
};
/* Definitions for t_CURTAIN */
osThreadId_t t_CURTAINHandle;
const osThreadAttr_t t_CURTAIN_attributes = {
  .name = "t_CURTAIN",
  .stack_size = 256 * 4,
  .priority = (osPriority_t) osPriorityBelowNormal7,
};
/* Definitions for t_update_encoder */
osThreadId_t t_update_encoderHandle;
const osThreadAttr_t t_update_encoder_attributes = {
  .name = "t_update_encoder",
  .stack_size = 512 * 4,
  .priority = (osPriority_t) osPriorityRealtime,
};
/* Definitions for t_simulate_periodic */
osThreadId_t t_simulate_periodicHandle;
const osThreadAttr_t t_simulate_periodic_attributes = {
  .name = "t_simulate_periodic",
  .stack_size = 512 * 4,
  .priority = (osPriority_t) osPriorityAboveNormal,
};
/* Definitions for command_rx_queue */
osMessageQueueId_t command_rx_queueHandle;
const osMessageQueueAttr_t command_rx_queue_attributes = {
  .name = "command_rx_queue"
};
/* Definitions for RPI_queue */
osMessageQueueId_t RPI_queueHandle;
const osMessageQueueAttr_t RPI_queue_attributes = {
  .name = "RPI_queue"
};
/* Definitions for KEYENCE_queue */
osMessageQueueId_t KEYENCE_queueHandle;
const osMessageQueueAttr_t KEYENCE_queue_attributes = {
  .name = "KEYENCE_queue"
};
/* Definitions for FG1_queue */
osMessageQueueId_t FG1_queueHandle;
const osMessageQueueAttr_t FG1_queue_attributes = {
  .name = "FG1_queue"
};
/* Definitions for classifier_queue */
osMessageQueueId_t classifier_queueHandle;
const osMessageQueueAttr_t classifier_queue_attributes = {
  .name = "classifier_queue"
};
/* Definitions for orientation_queue */
osMessageQueueId_t orientation_queueHandle;
const osMessageQueueAttr_t orientation_queue_attributes = {
  .name = "orientation_queue"
};
/* Definitions for DISCARD_queue */
osMessageQueueId_t DISCARD_queueHandle;
const osMessageQueueAttr_t DISCARD_queue_attributes = {
  .name = "DISCARD_queue"
};
/* Definitions for message_debug_queue */
osMessageQueueId_t message_debug_queueHandle;
const osMessageQueueAttr_t message_debug_queue_attributes = {
  .name = "message_debug_queue"
};
/* Definitions for FG2_queue */
osMessageQueueId_t FG2_queueHandle;
const osMessageQueueAttr_t FG2_queue_attributes = {
  .name = "FG2_queue"
};
/* Definitions for FG3_queue */
osMessageQueueId_t FG3_queueHandle;
const osMessageQueueAttr_t FG3_queue_attributes = {
  .name = "FG3_queue"
};
/* Definitions for FG4_queue */
osMessageQueueId_t FG4_queueHandle;
const osMessageQueueAttr_t FG4_queue_attributes = {
  .name = "FG4_queue"
};
/* Definitions for tx_tcp_queue */
osMessageQueueId_t tx_tcp_queueHandle;
const osMessageQueueAttr_t tx_tcp_queue_attributes = {
  .name = "tx_tcp_queue"
};
/* Definitions for CURTAIN_queue */
osMessageQueueId_t CURTAIN_queueHandle;
const osMessageQueueAttr_t CURTAIN_queue_attributes = {
  .name = "CURTAIN_queue"
};
/* Definitions for timer_simulate_conveyor */
osTimerId_t timer_simulate_conveyorHandle;
const osTimerAttr_t timer_simulate_conveyor_attributes = {
  .name = "timer_simulate_conveyor"
};
/* Definitions for timer_watch_queues */
osTimerId_t timer_watch_queuesHandle;
const osTimerAttr_t timer_watch_queues_attributes = {
  .name = "timer_watch_queues"
};
/* Definitions for timer_update_encoder */
osTimerId_t timer_update_encoderHandle;
const osTimerAttr_t timer_update_encoder_attributes = {
  .name = "timer_update_encoder"
};
/* Definitions for timer_simulate_periodic_oc */
osTimerId_t timer_simulate_periodic_ocHandle;
const osTimerAttr_t timer_simulate_periodic_oc_attributes = {
  .name = "timer_simulate_periodic_oc"
};
/* Definitions for mutex_sample_conveyor */
osMutexId_t mutex_sample_conveyorHandle;
const osMutexAttr_t mutex_sample_conveyor_attributes = {
  .name = "mutex_sample_conveyor"
};
/* Definitions for mutex_encoder_hardware */
osMutexId_t mutex_encoder_hardwareHandle;
const osMutexAttr_t mutex_encoder_hardware_attributes = {
  .name = "mutex_encoder_hardware"
};
/* Definitions for mutex_encoder_cascade */
osMutexId_t mutex_encoder_cascadeHandle;
const osMutexAttr_t mutex_encoder_cascade_attributes = {
  .name = "mutex_encoder_cascade"
};
void SystemClock_Config(void);
static void MX_GPIO_Init(void);
static void MX_UART5_Init(void);
static void MX_USART6_UART_Init(void);
static void MX_USART3_UART_Init(void);
static void MX_TIM1_Init(void);
static void MX_TIM3_Init(void);
static void MX_TIM4_Init(void);
static void MX_TIM5_Init(void);
void StartDefaultTask(void *argument);
void f_RPI_watch(void *argument);
void f_KEYENCE_watch(void *argument);
void f_FG1_wach(void *argument);
void f_FG2_wach(void *argument);
void f_FG3_wach(void *argument);
void f_FG4_wach(void *argument);
void f_DISCARD(void *argument);
void f_command_handl(void *argument);
void f_send_tcp(void *argument);
void f_recv_tcp(void *argument);
void f_conn_tcp_RPI(void *argument);
void f_conn_tcp_KEYENCE(void *argument);
void f_conn_tcp_FG1(void *argument);
void f_simulate_conveyor(void *argument);
void f_debug_mssgs(void *argument);
void f_CURTAIN(void *argument);
void f_update_encoder(void *argument);
void f_simulate_periodic(void *argument);
void callback_timer_simulate_conveyor(void *argument);
void callback_timer_watch_queues(void *argument);
void callback_timer_update_encoder(void *argument);
void callback_timer_simulate_periodic_oc(void *argument);

/* USER CODE BEGIN PFP */

void HAL_GPIO_EXTI_Callback(uint16_t GPIO_Pin)
{
    if (GPIO_Pin == OC_EXTI_PIN)
    {
    	callback_trigger_optical_curtain_IT();
    }
}
/* USER CODE END PFP */

/**
  * @brief  The application entry point.
  * @retval int
  */
int main(void)
{
  /* MCU Configuration--------------------------------------------------------*/

  /* Reset of all peripherals, Initializes the Flash interface and the Systick. */
  HAL_Init();

  /* Configure the system clock */
  SystemClock_Config();

  /* Initialize all configured peripherals */
  MX_GPIO_Init();
  MX_UART5_Init();
  MX_USART6_UART_Init();
  MX_USART3_UART_Init();
  MX_TIM1_Init();
  MX_TIM3_Init();
  MX_TIM4_Init();
  MX_TIM5_Init();
  /* USER CODE BEGIN 2 */
  huart_CLI_debug = &huart3;
  huart_CLI_CM4_main = &huart5;
  huart_CLI_CM4_second = &huart6;

  if(USE_UART_EXT) HAL_UART_Receive_IT(huart_CLI_debug, (uint8_t*) &(cli_uart_debug.rxBuffer), 1);
  if(USE_UART_CM4_MAIN) HAL_UART_Receive_IT(huart_CLI_CM4_main, (uint8_t*) &(cli_uart_CM4_main.rxBuffer), 1);
  if(USE_UART_CM4_SECN) HAL_UART_Receive_IT(huart_CLI_CM4_second, (uint8_t*) &(cli_uart_CM4_second.rxBuffer), 1);
  /* USER CODE END 2 */

  /* Init scheduler */
  osKernelInitialize();
  /* Create the mutex(es) */
  /* creation of mutex_sample_conveyor */
  mutex_sample_conveyorHandle = osMutexNew(&mutex_sample_conveyor_attributes);

  /* creation of mutex_encoder_hardware */
  mutex_encoder_hardwareHandle = osMutexNew(&mutex_encoder_hardware_attributes);

  /* creation of mutex_encoder_cascade */
  mutex_encoder_cascadeHandle = osMutexNew(&mutex_encoder_cascade_attributes);

  /* USER CODE BEGIN RTOS_MUTEX */
  /* add mutexes, ... */
  /* USER CODE END RTOS_MUTEX */

  /* USER CODE BEGIN RTOS_SEMAPHORES */
  /* add semaphores, ... */
  /* USER CODE END RTOS_SEMAPHORES */

  /* Create the timer(s) */
  /* creation of timer_simulate_conveyor */
  timer_simulate_conveyorHandle = osTimerNew(callback_timer_simulate_conveyor, osTimerPeriodic, NULL, &timer_simulate_conveyor_attributes);

  /* creation of timer_watch_queues */
  timer_watch_queuesHandle = osTimerNew(callback_timer_watch_queues, osTimerPeriodic, NULL, &timer_watch_queues_attributes);

  /* creation of timer_update_encoder */
  timer_update_encoderHandle = osTimerNew(callback_timer_update_encoder, osTimerPeriodic, NULL, &timer_update_encoder_attributes);

  /* creation of timer_simulate_periodic_oc */
  timer_simulate_periodic_ocHandle = osTimerNew(callback_timer_simulate_periodic_oc, osTimerPeriodic, NULL, &timer_simulate_periodic_oc_attributes);

  /* USER CODE BEGIN RTOS_TIMERS */
  /* start timers, add new ones, ... */
  /* USER CODE END RTOS_TIMERS */

  /* Create the queue(s) */
  /* creation of command_rx_queue */
  command_rx_queueHandle = osMessageQueueNew (30, sizeof(queue_commandRx), &command_rx_queue_attributes);

  /* creation of RPI_queue */
  RPI_queueHandle = osMessageQueueNew (3, sizeof(float), &RPI_queue_attributes);

  /* creation of KEYENCE_queue */
  KEYENCE_queueHandle = osMessageQueueNew (4, sizeof(queue_inter_stations), &KEYENCE_queue_attributes);

  /* creation of FG1_queue */
  FG1_queueHandle = osMessageQueueNew (4, sizeof(queue_inter_stations), &FG1_queue_attributes);

  /* creation of classifier_queue */
  classifier_queueHandle = osMessageQueueNew (3, sizeof(queue_stations_tcp), &classifier_queue_attributes);

  /* creation of orientation_queue */
  orientation_queueHandle = osMessageQueueNew (3, sizeof(queue_stations_tcp), &orientation_queue_attributes);

  /* creation of DISCARD_queue */
  DISCARD_queueHandle = osMessageQueueNew (200, sizeof(float), &DISCARD_queue_attributes);

  /* creation of message_debug_queue */
  message_debug_queueHandle = osMessageQueueNew (50, sizeof(message_debug), &message_debug_queue_attributes);

  /* creation of FG2_queue */
  FG2_queueHandle = osMessageQueueNew (3, sizeof(float), &FG2_queue_attributes);

  /* creation of FG3_queue */
  FG3_queueHandle = osMessageQueueNew (3, sizeof(float), &FG3_queue_attributes);

  /* creation of FG4_queue */
  FG4_queueHandle = osMessageQueueNew (3, sizeof(float), &FG4_queue_attributes);

  /* creation of tx_tcp_queue */
  tx_tcp_queueHandle = osMessageQueueNew (10, sizeof(queue_tx_rx_tcp), &tx_tcp_queue_attributes);

  /* creation of CURTAIN_queue */
  CURTAIN_queueHandle = osMessageQueueNew (60, sizeof(bool), &CURTAIN_queue_attributes);

  /* USER CODE BEGIN RTOS_QUEUES */
  /* add queues, ... */
  /* USER CODE END RTOS_QUEUES */

  /* Create the thread(s) */
  /* creation of defaultTask */
  defaultTaskHandle = osThreadNew(StartDefaultTask, NULL, &defaultTask_attributes);

  /* creation of t_RPI_watch */
  t_RPI_watchHandle = osThreadNew(f_RPI_watch, NULL, &t_RPI_watch_attributes);

  /* creation of t_KEYENCE_watch */
  t_KEYENCE_watchHandle = osThreadNew(f_KEYENCE_watch, NULL, &t_KEYENCE_watch_attributes);

  /* creation of t_FG1_wach */
  t_FG1_wachHandle = osThreadNew(f_FG1_wach, NULL, &t_FG1_wach_attributes);

  /* creation of t_FG2_wach */
  t_FG2_wachHandle = osThreadNew(f_FG2_wach, NULL, &t_FG2_wach_attributes);

  /* creation of t_FG3_wach */
  t_FG3_wachHandle = osThreadNew(f_FG3_wach, NULL, &t_FG3_wach_attributes);

  /* creation of t_FG4_wach */
  t_FG4_wachHandle = osThreadNew(f_FG4_wach, NULL, &t_FG4_wach_attributes);

  /* creation of t_DISCARD */
  t_DISCARDHandle = osThreadNew(f_DISCARD, NULL, &t_DISCARD_attributes);

  /* creation of t_command_hand */
  t_command_handHandle = osThreadNew(f_command_handl, NULL, &t_command_hand_attributes);

  /* creation of t_send_tcp */
  t_send_tcpHandle = osThreadNew(f_send_tcp, NULL, &t_send_tcp_attributes);

  /* creation of t_recv_tcp */
  t_recv_tcpHandle = osThreadNew(f_recv_tcp, NULL, &t_recv_tcp_attributes);

  /* creation of t_conn_tcp_RPI */
  t_conn_tcp_RPIHandle = osThreadNew(f_conn_tcp_RPI, NULL, &t_conn_tcp_RPI_attributes);

  /* creation of t_conn_tcp_KEYENCE */
  t_conn_tcp_KEYENCEHandle = osThreadNew(f_conn_tcp_KEYENCE, NULL, &t_conn_tcp_KEYENCE_attributes);

  /* creation of t_conn_tcp_FG1 */
  t_conn_tcp_FG1Handle = osThreadNew(f_conn_tcp_FG1, NULL, &t_conn_tcp_FG1_attributes);

  /* creation of t_simulate_conveyor */
  t_simulate_conveyorHandle = osThreadNew(f_simulate_conveyor, NULL, &t_simulate_conveyor_attributes);

  /* creation of t_debug_mssgs */
  t_debug_mssgsHandle = osThreadNew(f_debug_mssgs, NULL, &t_debug_mssgs_attributes);

  /* creation of t_CURTAIN */
  t_CURTAINHandle = osThreadNew(f_CURTAIN, NULL, &t_CURTAIN_attributes);

  /* creation of t_update_encoder */
  t_update_encoderHandle = osThreadNew(f_update_encoder, NULL, &t_update_encoder_attributes);

  /* creation of t_simulate_periodic */
  t_simulate_periodicHandle = osThreadNew(f_simulate_periodic, NULL, &t_simulate_periodic_attributes);

  /* USER CODE BEGIN RTOS_THREADS */


	//Encoder
	HAL_TIM_Encoder_Start(&htim4, TIM_CHANNEL_ALL);
	HAL_TIM_Base_Start(&htim5);
	__HAL_TIM_SET_COUNTER(&htim4,0);
	__HAL_TIM_SET_COUNTER(&htim5,0);
	if(USE_CASCADE_BY_SOFTWARE) osTimerStart(timer_update_encoderHandle,get_ticks_from_ms(TIM_UPDT_CSCD_SOFT));

	//tcpclient_init();
	if (USE_SIMULATOR_CONVEYOR)osTimerStart(timer_simulate_conveyorHandle, get_ticks_from_ms(TIM_SIMUL_STEP)); // SIM_STEP_TIME en ms
	//osTimerStart(timer_watch_queuesHandle, get_ticks_from_ms(TIM_SLEEP_QUEUES));
	vTaskResume(t_command_handHandle);

	//Simulator_periodic
	osTimerStart(timer_simulate_periodic_ocHandle, get_ms_from_ticks(get_ticks_from_ms(TIM_OC_EVENTS_SIM)));

  /* USER CODE END RTOS_THREADS */
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

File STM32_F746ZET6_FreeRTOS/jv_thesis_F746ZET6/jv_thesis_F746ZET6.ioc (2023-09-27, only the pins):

Mcu.UserName=STM32F746ZETx
PA1.Signal=ETH_REF_CLK
PA11.GPIO_Label=USB_DM_- 
PA11.Signal=USB_OTG_FS_DM
PA12.GPIO_Label=USB_DM_+ 
PA12.Signal=USB_OTG_FS_DP
PA13.GPIO_Label=SWDIO
PA13.Signal=SYS_JTMS-SWDIO
PA14.GPIO_Label=SWCLK
PA14.Signal=SYS_JTCK-SWCLK
PA2.Signal=ETH_MDIO
PA7.Signal=ETH_CRS_DV
PB0.GPIO_Label=INDICATOR_R
PB0.Signal=GPIO_Output
PB1.GPIO_Label=INDICATOR_G
PB1.Signal=GPIO_Output
PB13.Signal=ETH_TXD1
PB14.GPIO_Label=ENC_24V_1 
PB14.Signal=GPXTI14
PB15.GPIO_Label=ENC_24V_2 
PB15.Signal=GPXTI15
PB2.GPIO_Label=INDICATOR_B
PB2.Signal=GPIO_Output
PB3.GPIO_Label=SWO
PB3.Signal=SYS_JTDO-SWO
PB4.GPIO_Label=SIMULATE_ENCODER_CH1
PB4.Signal=S_TIM3_CH1
PC1.Signal=ETH_MDC
PC12.Signal=UART5_TX
PC4.Signal=ETH_RXD0
PC5.Signal=ETH_RXD1
PC6.Signal=USART6_TX
PC7.Signal=USART6_RX
PD10.GPIO_Label=ENC_24V_3 
PD10.Signal=GPXTI10
PD11.GPIO_Label=ENC_24V_4 
PD11.Signal=GPXTI11
PD12.GPIO_Label=ENC_24V_5 
PD12.Signal=S_TIM4_CH1
PD13.GPIO_Label=ENC_24V_6 
PD13.Signal=S_TIM4_CH2
PD2.Signal=UART5_RX
PD8.Signal=USART3_TX
PD9.Signal=USART3_RX
PE10.GPIO_Label=TRIGGER_24V_6 
PE10.Signal=GPIO_Output
PE11.GPIO_Label=TRIGGER_24V_5 
PE11.Signal=GPIO_Output
PE12.GPIO_Label=TRIGGER_24V_4 
PE12.Signal=GPIO_Output
PE13.GPIO_Label=SIMULATE_ENCODER_CH2
PE13.Signal=S_TIM1_CH3
PE14.GPIO_Label=TRIGGER_24V_2 
PE14.Signal=GPIO_Output
PE15.GPIO_Label=TRIGGER_24V_1 
PE15.Signal=GPIO_Output
PE3.GPIO_Label=TRIGGER_xxV_12 
PE3.Signal=GPIO_Output
PE4.GPIO_Label=TRIGGER_xxV_11 
PE4.Signal=GPIO_Output
PE5.GPIO_Label=TRIGGER_xxV_10 
PE5.Signal=GPIO_Output
PE6.GPIO_Label=TRIGGER_xxV_9 
PE6.Signal=GPIO_Output
PE8.GPIO_Label=TRIGGER_24V_8 
PE8.Signal=GPIO_Output
PE9.GPIO_Label=TRIGGER_24V_7 
PE9.Signal=GPIO_Output
PF13.GPIO_Label=SIMULATE_OPTICAL_CURTAIN 
PF13.Signal=GPIO_Output
PG11.Signal=ETH_TX_EN
PG13.Signal=ETH_TXD0
PH0/OSC_IN.Signal=RCC_OSC_IN
PH1/OSC_OUT.Signal=RCC_OSC_OUT

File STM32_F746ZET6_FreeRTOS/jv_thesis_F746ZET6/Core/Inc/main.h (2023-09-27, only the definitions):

#define TRIGGER_xxV_12_Pin GPIO_PIN_3
#define TRIGGER_xxV_12_GPIO_Port GPIOE
#define TRIGGER_xxV_11_Pin GPIO_PIN_4
#define TRIGGER_xxV_11_GPIO_Port GPIOE
#define TRIGGER_xxV_10_Pin GPIO_PIN_5
#define TRIGGER_xxV_10_GPIO_Port GPIOE
#define TRIGGER_xxV_9_Pin GPIO_PIN_6
#define TRIGGER_xxV_9_GPIO_Port GPIOE
#define INDICATOR_R_Pin GPIO_PIN_0
#define INDICATOR_R_GPIO_Port GPIOB
#define INDICATOR_G_Pin GPIO_PIN_1
#define INDICATOR_G_GPIO_Port GPIOB
#define INDICATOR_B_Pin GPIO_PIN_2
#define INDICATOR_B_GPIO_Port GPIOB
#define SIMULATE_OPTICAL_CURTAIN_Pin GPIO_PIN_13
#define SIMULATE_OPTICAL_CURTAIN_GPIO_Port GPIOF
#define TRIGGER_24V_8_Pin GPIO_PIN_8
#define TRIGGER_24V_8_GPIO_Port GPIOE
#define TRIGGER_24V_7_Pin GPIO_PIN_9
#define TRIGGER_24V_7_GPIO_Port GPIOE
#define TRIGGER_24V_6_Pin GPIO_PIN_10
#define TRIGGER_24V_6_GPIO_Port GPIOE
#define TRIGGER_24V_5_Pin GPIO_PIN_11
#define TRIGGER_24V_5_GPIO_Port GPIOE
#define TRIGGER_24V_4_Pin GPIO_PIN_12
#define TRIGGER_24V_4_GPIO_Port GPIOE
#define SIMULATE_ENCODER_CH2_Pin GPIO_PIN_13
#define SIMULATE_ENCODER_CH2_GPIO_Port GPIOE
#define TRIGGER_24V_2_Pin GPIO_PIN_14
#define TRIGGER_24V_2_GPIO_Port GPIOE
#define TRIGGER_24V_1_Pin GPIO_PIN_15
#define TRIGGER_24V_1_GPIO_Port GPIOE
#define ENC_24V_1_Pin GPIO_PIN_14
#define ENC_24V_1_GPIO_Port GPIOB
#define ENC_24V_1_EXTI_IRQn EXTI15_10_IRQn
#define ENC_24V_2_Pin GPIO_PIN_15
#define ENC_24V_2_GPIO_Port GPIOB
#define ENC_24V_2_EXTI_IRQn EXTI15_10_IRQn
#define ENC_24V_3_Pin GPIO_PIN_10
#define ENC_24V_3_GPIO_Port GPIOD
#define ENC_24V_3_EXTI_IRQn EXTI15_10_IRQn
#define ENC_24V_4_Pin GPIO_PIN_11
#define ENC_24V_4_GPIO_Port GPIOD
#define ENC_24V_4_EXTI_IRQn EXTI15_10_IRQn
#define ENC_24V_5_Pin GPIO_PIN_12
#define ENC_24V_5_GPIO_Port GPIOD
#define ENC_24V_6_Pin GPIO_PIN_13
#define ENC_24V_6_GPIO_Port GPIOD
#define USB_DM___Pin GPIO_PIN_11
#define USB_DM___GPIO_Port GPIOA
#define USB_DM__A12_Pin GPIO_PIN_12
#define USB_DM__A12_GPIO_Port GPIOA
#define SWDIO_Pin GPIO_PIN_13
#define SWDIO_GPIO_Port GPIOA
#define SWCLK_Pin GPIO_PIN_14
#define SWCLK_GPIO_Port GPIOA
#define SWO_Pin GPIO_PIN_3
#define SWO_GPIO_Port GPIOB
#define SIMULATE_ENCODER_CH1_Pin GPIO_PIN_4
#define SIMULATE_ENCODER_CH1_GPIO_Port GPIOB

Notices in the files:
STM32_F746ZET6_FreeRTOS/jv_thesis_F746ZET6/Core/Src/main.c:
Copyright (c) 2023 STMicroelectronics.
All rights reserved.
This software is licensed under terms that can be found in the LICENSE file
